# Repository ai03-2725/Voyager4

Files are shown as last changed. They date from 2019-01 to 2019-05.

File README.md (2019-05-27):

# Voyager4
A tiny, fully featured 4-key macropad PCB

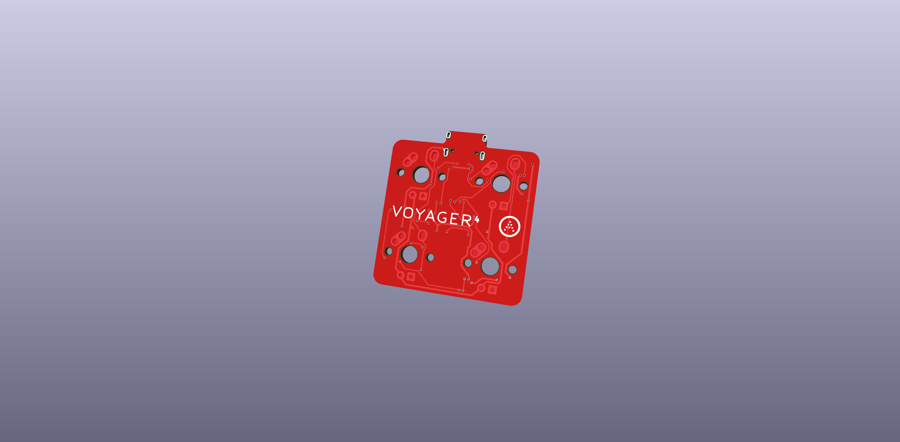
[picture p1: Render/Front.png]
Render


#### In light of recent claims that I am 100% liable for any of my open source PCBs, I am adding this disclaimer.
#### I provide these PCBs as a reference for designing keyboard PCBs. Using them within your projects will require a will to do research of one's own and to learn the workings of them, potentially fixing issues if they exist.
# I provide these PCBs without liability and without any guarantees regarding functionality, as expressed in the MIT license under which all of these PCBs are licensed.

### Features
* In-switch LED backlighting
* RGB underglow
* Over-current and static discharge protection
* Fully open-source
* Absolutely tiny

### The Voyager PCB Family
The Voyager PCBs offer fully featured PCBs fit for any keyboard, whether mass production or high-end.

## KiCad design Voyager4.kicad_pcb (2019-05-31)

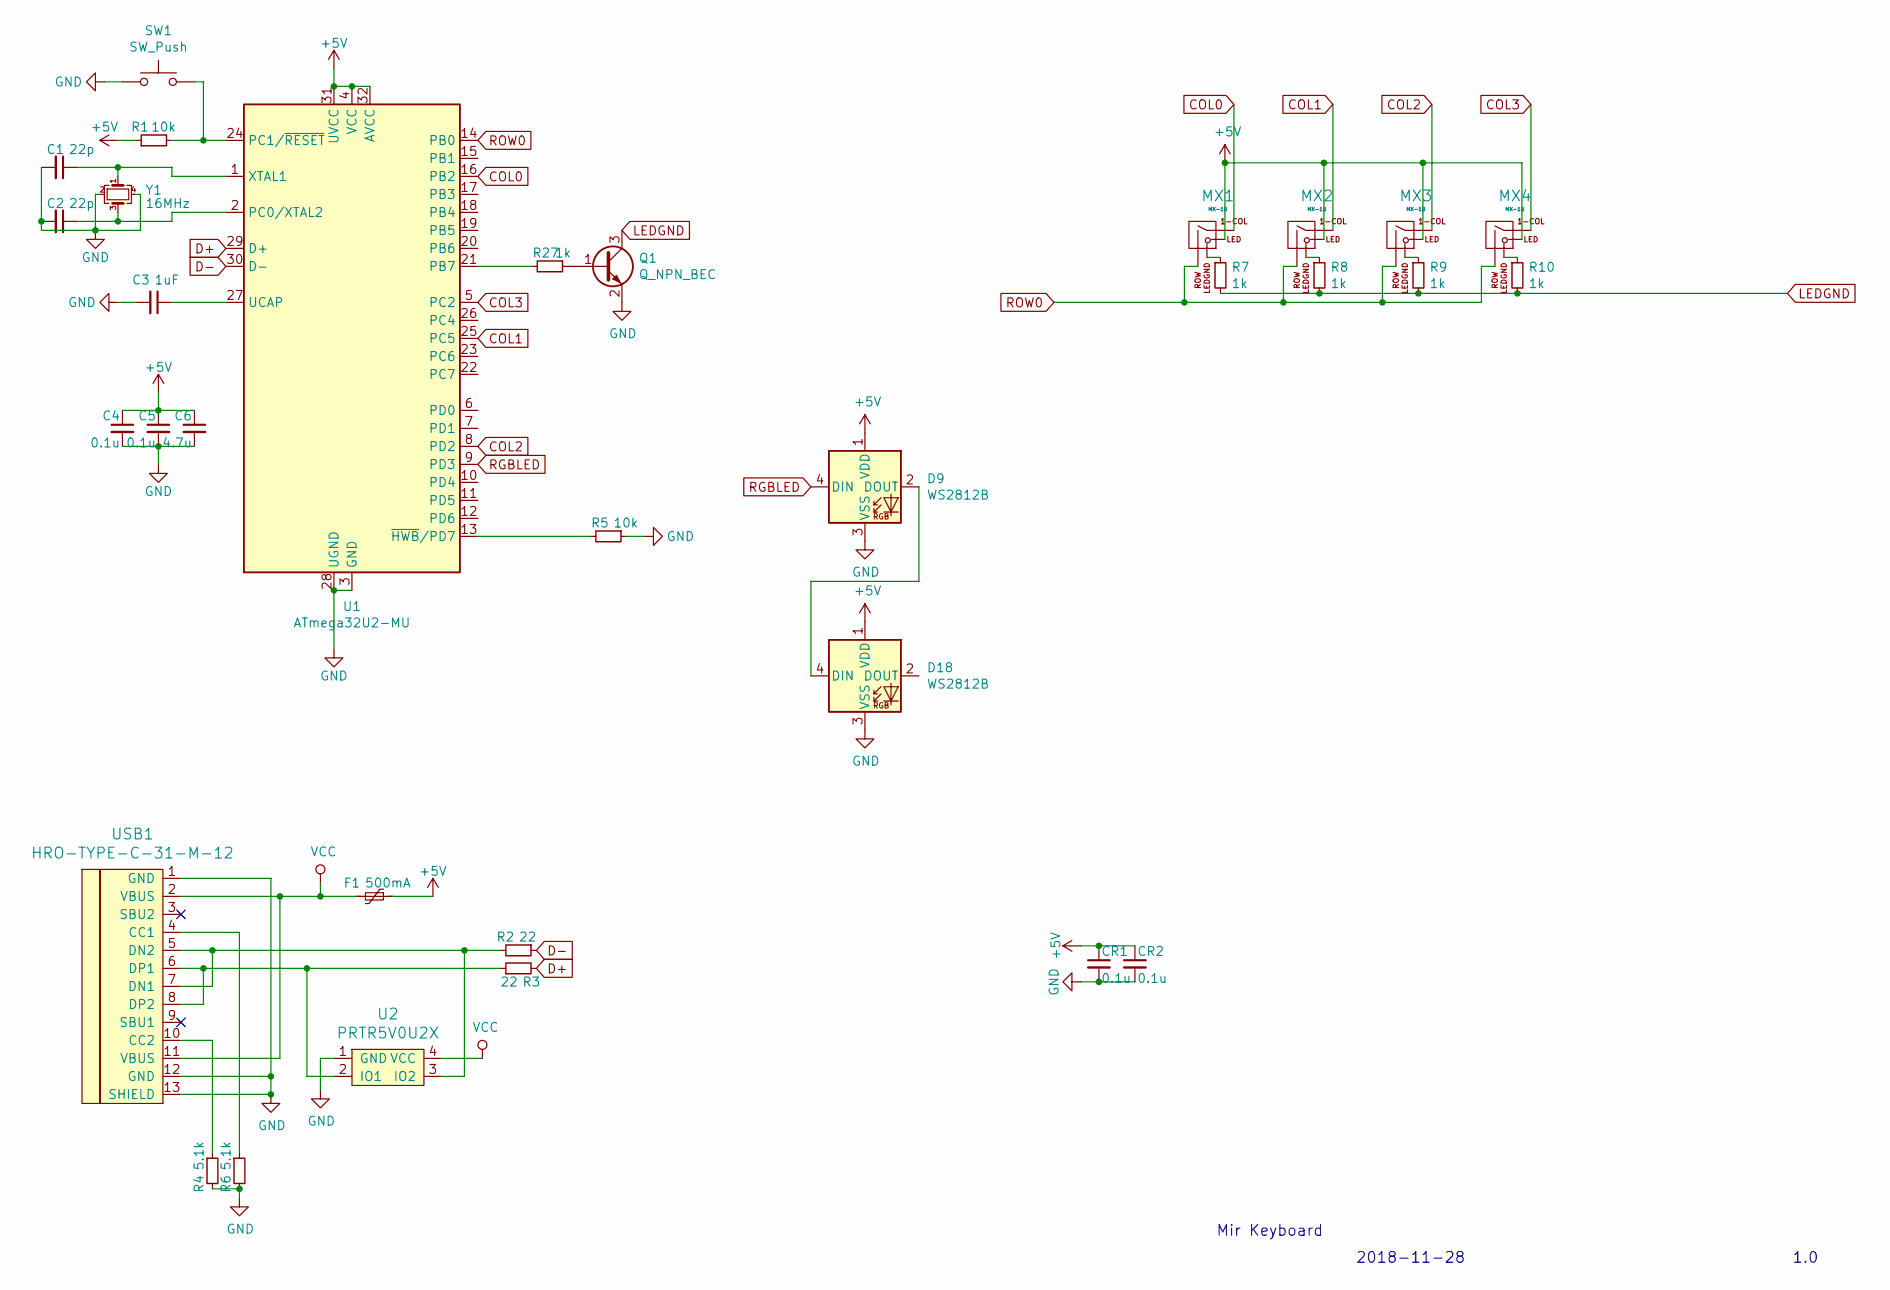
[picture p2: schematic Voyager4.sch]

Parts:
C1, C2: 22p; C_0603
C3: 1uF; C_0603
C4, C5: 0.1u; C_0603
C6: 4.7u; C_0603
CR1, CR2: 0.1u; C_0603
D9, D18: WS2812B; LED_WS2812B-PLCC4
F1: 500mA; Fuse_SMD1206_Reflow
MX1, MX2, MX3, MX4: MX-1U
Q1: Q_NPN_BEC; SOT-23
R1, R5: 10k; R_0805
R2, R3: 22; R_0805
R4, R6: 5.1k; R_0805
R7, R8, R9, R10, R27: 1k; R_0805
SW1: SW_Push; Jumper-UserFriendly-Small
U1: ATmega32U2-MU; QFN-32-1EP_5x5mm_Pitch0.5mm
U2: PRTR5V0U2X; SOT143B
USB1: HRO-TYPE-C-31-M-12; HRO-TYPE-C-31-M-12-Assembly
Y1: 16MHz; Crystal_SMD_3225-4pin_3.2x2.5mm

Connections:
+5V: C4.1, C5.1, C6.1, CR1.1, CR2.1, D9.1 (VDD), D18.1 (VDD), F1.1, MX1.3 (LED), MX2.3 (LED), MX3.3 (LED), MX4.3 (LED), R1.1, U1.4 (VCC), U1.31 (UVCC), U1.32 (AVCC)
COL0: MX1.1 (COL), U1.16 (PB2)
COL1: MX2.1 (COL), U1.25 (PC5)
COL2: MX3.1 (COL), U1.8 (PD2)
COL3: MX4.1 (COL), U1.5 (PC2)
D+: R3.2, U1.29 (D+)
D-: R2.1, U1.30 (D-)
GND: C1.2, C2.2, C3.2, C4.2, C5.2, C6.2, CR1.2, CR2.2, D9.3 (VSS), D18.3 (VSS), Q1.2 (E), R4.2, R5.1, R6.2, SW1.1, U1.3 (GND), U1.28 (UGND), U1.33 (GND), U2.1 (GND), USB1.1 (GND), USB1.12 (GND), USB1.13 (SHIELD), Y1.2, Y1.4
LEDGND: Q1.3 (C), R7.2, R8.2, R9.2, R10.2
unnamed: C1.1, U1.1 (XTAL1), Y1.1
unnamed: C2.1, U1.2 (PC0/XTAL2), Y1.3
unnamed: C3.1, U1.27 (UCAP)
unnamed: D9.2 (DOUT), D18.4 (DIN)
unnamed: MX1.4 (LEDGND), R7.1
unnamed: MX2.4 (LEDGND), R8.1
unnamed: MX3.4 (LEDGND), R9.1
unnamed: MX4.4 (LEDGND), R10.1
unnamed: Q1.1 (B), R27.1
unnamed: R1.2, SW1.2, U1.24 (PC1/~RESET)
unnamed: R2.2, U2.3 (IO2), USB1.5 (DN2), USB1.7 (DN1)
unnamed: R3.1, U2.2 (IO1), USB1.6 (DP1), USB1.8 (DP2)
unnamed: R4.1, USB1.10 (CC2)
unnamed: R5.2, U1.13 (~HWB~/PD7)
unnamed: R6.1, USB1.4 (CC1)
unnamed: R27.2, U1.21 (PB7)
RGBLED: D9.4 (DIN), U1.9 (PD3)
ROW0: MX1.2 (ROW), MX2.2 (ROW), MX3.2 (ROW), MX4.2 (ROW), U1.14 (PB0)
VCC: F1.2, U2.4 (VCC), USB1.2 (VBUS), USB1.11 (VBUS)

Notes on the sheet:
Mir Keyboard
2018-11-28
1.0

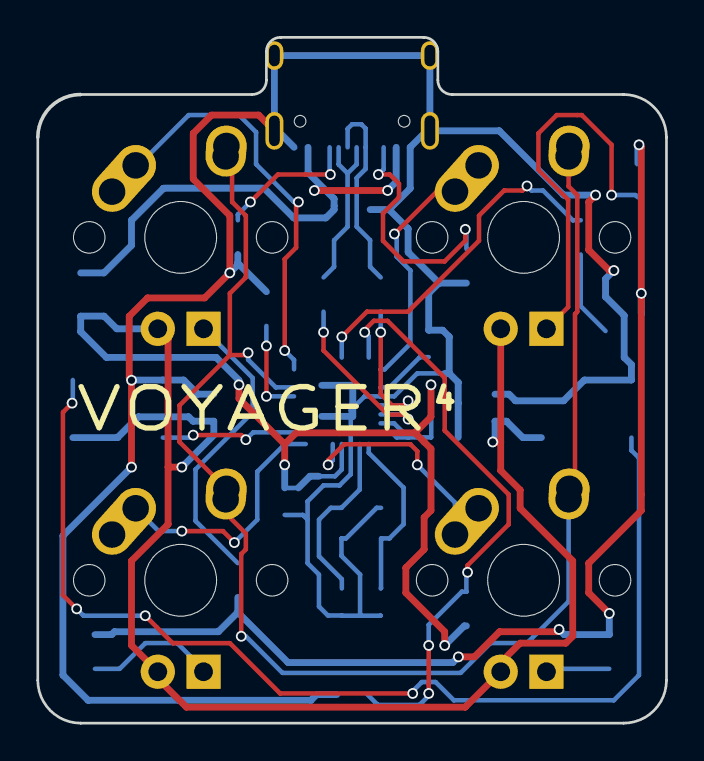
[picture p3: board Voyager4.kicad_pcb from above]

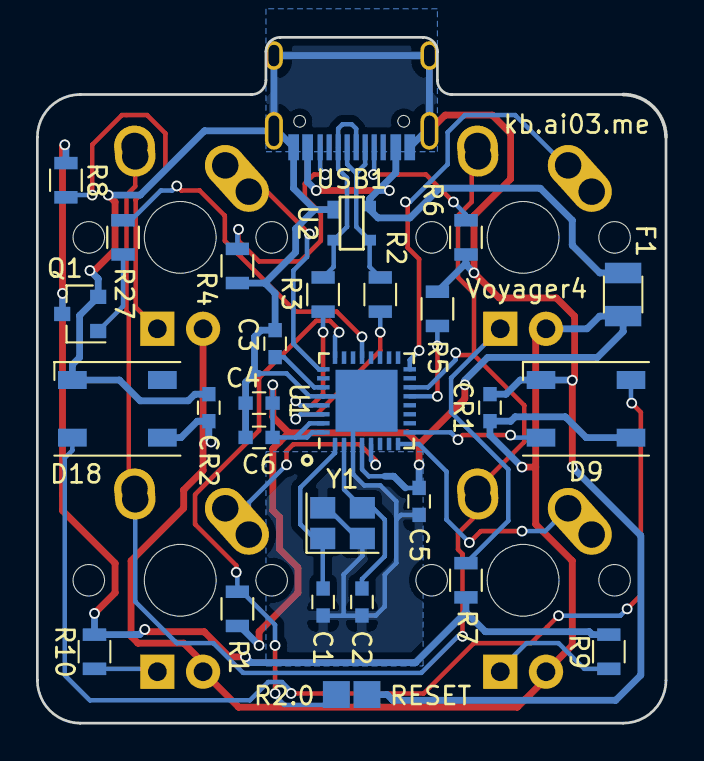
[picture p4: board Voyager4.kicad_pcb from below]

Board: 2 copper layers, 34.9 x 38.1 mm, 32 parts (28 on the bottom side), 28 nets.

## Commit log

2019-01-27 Build the PCB
    [Matrix.sch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]
2019-05-31 Repair project, rev 2.0
    [Voyager4-B_Cu.gbl, Voyager4-B_Mask.gbs, Voyager4-B_Paste.gbp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]
2019-05-31 Save progress
    [Voyager4.kicad_pcb]
